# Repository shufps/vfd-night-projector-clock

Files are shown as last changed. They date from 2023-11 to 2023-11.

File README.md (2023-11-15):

# vfd-night-clock



## Description

The VFD Night Projector Clock is the first and only (at the moment and to my knowledge 😁) night projecting clock that uses a VFD display.

When receiving one of the NOS IVL2-7/5 displays, I noticed that the illuminated area could fit in about full-format (24x36mm) what was standard in analogue photography.

For this reason there are plenty of old lenses (e.g. with M42 threading) out there that almost cost nothing anymore although they have impressive technical properties like 1:2.8 with f=135.

Moreover, they have a flange focal distance of 45.46mm which allows to build a relatively compact casing.



So here it is ... 🥳

This image shows a comparison between my old radio clock with projector and the VFD night clock projector:



The brighness is perfect in the night 👌 (but ofc barely visible at day)

If everything is adjusted properly, you even can see the grid on the digits:



## Properties

There are some methods how a VFD can be operated. After some prior experience with VFDs this is one of the easiest methods:

- isolated 24 DCDC converter for anode voltage. The V+ is connected to GND, so you have -24V on the board
- the positive gate/segment voltage is +3.3V. You easily can switch the positive gate/segment voltage with BSS84s from a STM32 with no additional parts what is the easiest solution. This gives a total gate / segment voltage of 27.3V
- AC Filament drive is done with a full-bridge made of a two channel MOSFET driver. The output is AC coupled and pulled to about -22V. Bias is adjustable (even could be used to change the brightness)



## STM32 Software

The STM32 software currently only supports a json-rpc via USB virtual COM port (CDC). Buttons are currently unused 🙈

There is python code that can 

- measure the clock accuracy
- set the time
- set the display state and auto-switch on/off

This are small examples that nicely demonstrate how to use the json-rpc.

## 3D case



The case was designed in a way that no supports are needed. The upper part is simply clipped on the lower part.

<!--
Ode to VFD Displays (Chatti4 2023)

Oh, relics of an era long past,<br>
Vacuum Fluorescent Displays, you hold fast.<br>
Born in Soviet realms, a technological feast,<br>
Your glasspunk aesthetics have never ceased.<br>

In your cylindrical tubes, a dance of light,<br>
A greenish-blue hue, softly bright.<br>
Your glow, a whisper from history's tide,<br>
In old devices, you reside with pride.<br>

You are the silent storytellers, bold,<br>
Of times when technology wasn't so cold.<br>
Your luminescent charm, a visual delight,<br>
In the stillness of rooms, you're the night's light.<br>

Through you, numbers and words gracefully flow,<br>
A retro display, a nostalgic glow.<br>
Your enduring spirit, a testament to time,<br>
In the world of screens, you're a verse, a rhyme.<br>

VFD, in your glass cocoon you lay,<br>
A visual symphony in green and gray.<br>
A bridge from the past, to the present you lead,<br>
A piece of history, in every glowing bead.<br>

In the march of progress, you're a quiet ode,<br>
A reminder of a less digital road.<br>
VFD displays, in you, the past does reside,<br>
A beautiful, forgotten technological stride.<br>
-->

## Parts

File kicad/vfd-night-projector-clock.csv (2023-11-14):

# | Reference | Qty | Value | Footprint | DNP | OrderNr | Distributor
1 | C1, C5, C6, C9, C15 | 5 | 100n | Capacitor_SMD:C_0805_2012Metric
2 | C2, C8, C10, C11, C13 | 5 | 10µF/50V | Capacitor_SMD:C_1206_3216Metric |  | 1276-6736-1-ND | D
3 | C3, C4 | 2 | 6pF | Capacitor_SMD:C_0805_2012Metric |  | 311-1095-1-ND | D
4 | C7, C12 | 2 | 10µ/50V | Capacitor_SMD:CP_Elec_5x5.4 |  | 732-8451-1-ND | D
5 | C14 | 1 | 1µ/50V | Capacitor_SMD:C_1206_3216Metric |  | 1276-2719-1-ND | D
6 | J1 | 1 | SWD | myfootprints:PinHeader_IDC_2x05_P1.27mm_Vertical_SMD |  |  | X
7 | P1 | 1 | MYUSB_B | Connector_USB:USB_Micro-B_Amphenol_10103594-0001LF_Horizontal |  | 609-4050-1-ND | D
8 | Q1, Q2, Q3, Q4, Q5, Q6, Q7, Q8, Q9, Q10, Q11, Q12, Q13, Q14 | 14 | BSS84 | Package_TO_SOT_SMD:SOT-23
9 | R1, R2 | 2 | 1k | Resistor_SMD:R_0805_2012Metric
10 | R3, R5 | 2 | 15R | Resistor_SMD:R_2010_5025Metric |  | RMCF2010JT15R0CT-ND | D
11 | R4, R7, R11, R12, R13, R14, R15, R16, R17, R18, R19, R20, R21, R22 | 14 | 47k | Resistor_SMD:R_0805_2012Metric
12 | R6 | 1 | 36k | Resistor_SMD:R_0805_2012Metric
13 | R8 | 1 | x | Resistor_SMD:R_0805_2012Metric | DNP |  | -
14 | R9, R26 | 2 | 12R | Resistor_SMD:R_2010_5025Metric |  | RMCF2010JT12R0CT-ND | D
15 | R10, R29 | 2 | 10R | Resistor_SMD:R_2010_5025Metric |  | RMCF2010JT10R0CT-ND | D
16 | R23 | 1 | 100k | Resistor_SMD:R_0805_2012Metric
17 | R24, R25 | 2 | 10k | Resistor_SMD:R_0805_2012Metric
18 | R27, R28 | 2 | 22 | Resistor_SMD:R_0805_2012Metric
19 | RV1 | 1 | 10k | Potentiometer_SMD:Potentiometer_Bourns_3269W_Vertical |  | 3269W-1-103LF-ND | D
20 | SW3, SW4, SW5 | 3 | SW_SPST | Button_Switch_THT:SW_Tactile_SPST_Angled_PTS645Vx83-2LFS |  | CKN9121-ND | D
21 | U1 | 1 | IVL2-7_5 | myfootprints:ILV2-5_7 |  |  | X
22 | U2 | 1 | TLV9301xDBV | Package_TO_SOT_SMD:SOT-23-5 |  | 296-TLV9301IDBVRCT-ND | D
23 | U3 | 1 | STM32L052K6Tx | Package_QFP:LQFP-32_7x7mm_P0.8mm |  | 497-14904-ND | D
24 | U4 | 1 | 2EDN7524F | Package_SO:SO-8_3.9x4.9mm_P1.27mm |  | 2EDN7524FXTMA1CT-ND | D
25 | U5 | 1 | IES0105S24 | myfootprints:IES0105S24-dcdc |  | 1470-IES0105S24-ND | D
26 | U6 | 1 | LM1117MP-3.3 | Package_TO_SOT_SMD:SOT-223-3_TabPin2 |  | LM1117MPX-3.3/NOPBCT-ND | D
27 | Y1 | 1 | Crystal | Crystal:Crystal_SMD_EuroQuartz_EQ161-2Pin_3.2x1.5mm |  | 535-15021-1-ND | D

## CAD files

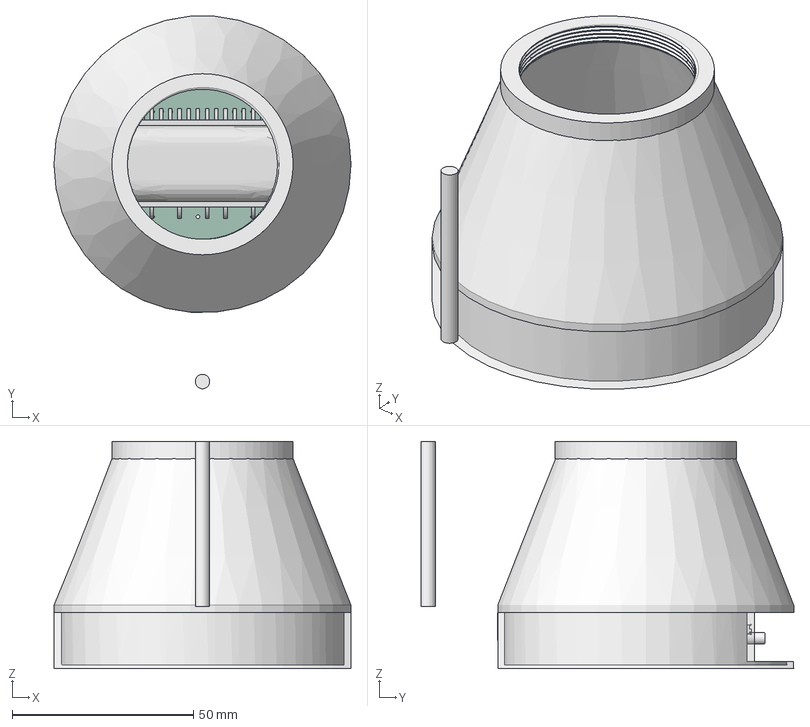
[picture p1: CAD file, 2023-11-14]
3d/case/case.FCStd
82.0 x 102.8 x 62.7 mm
Zylinder020
vfd1 PCB
M42test

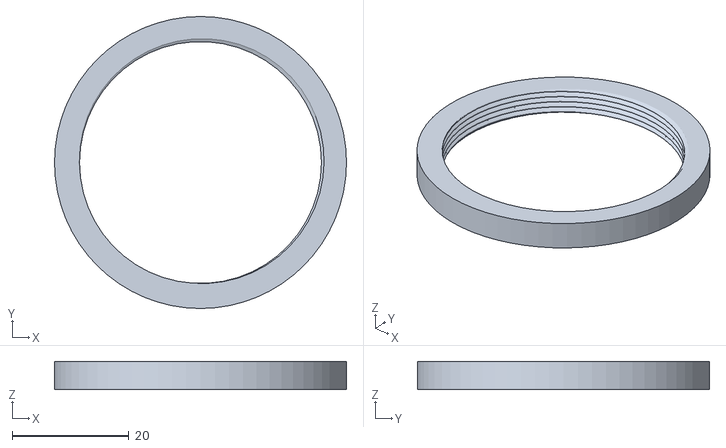
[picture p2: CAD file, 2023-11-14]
3d/openscad/M42test.stl
50.0 x 50.0 x 4.80

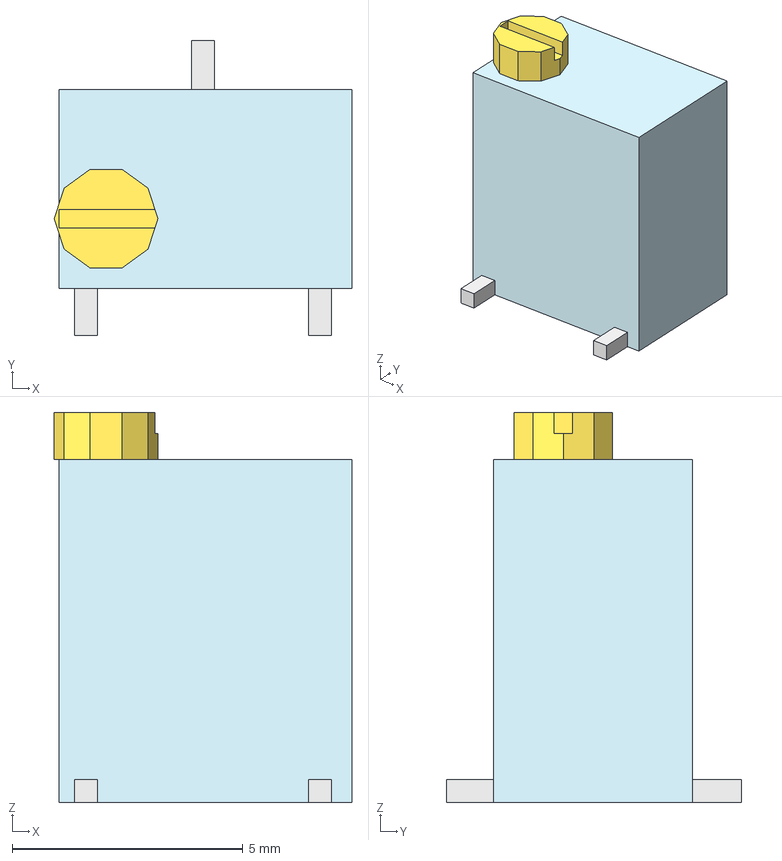
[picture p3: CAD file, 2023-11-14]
3d/3269-potentiometer.step
6.46 x 6.41 x 8.46 mm

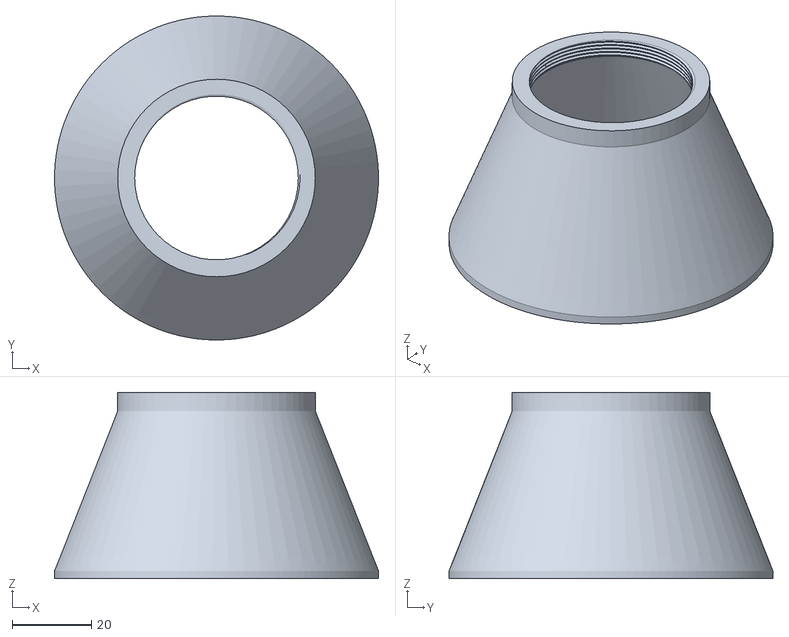
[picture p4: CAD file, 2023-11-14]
3d/case/case-top.stl
82.0 x 82.0 x 47.2

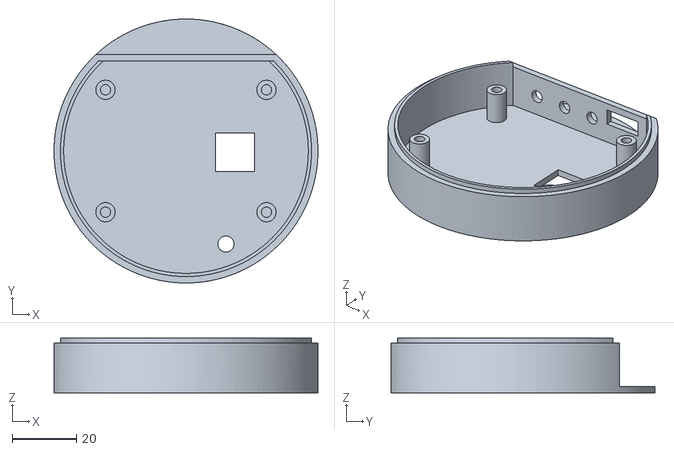
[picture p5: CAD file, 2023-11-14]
3d/case/case-bottom.stl
82.0 x 82.0 x 17.0

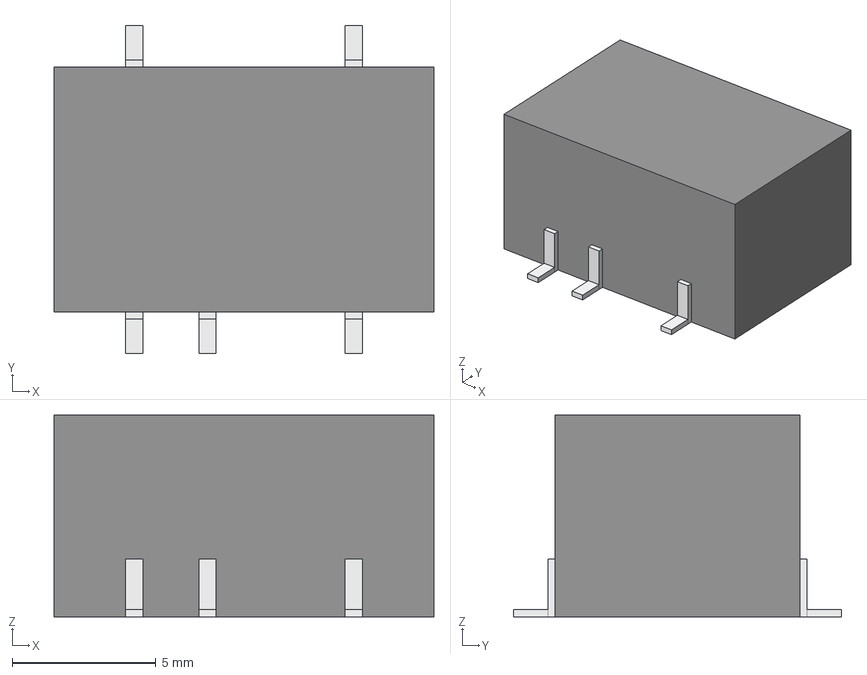
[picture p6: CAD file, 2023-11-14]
3d/dcdc.step
13.2 x 11.4 x 7.00 mm

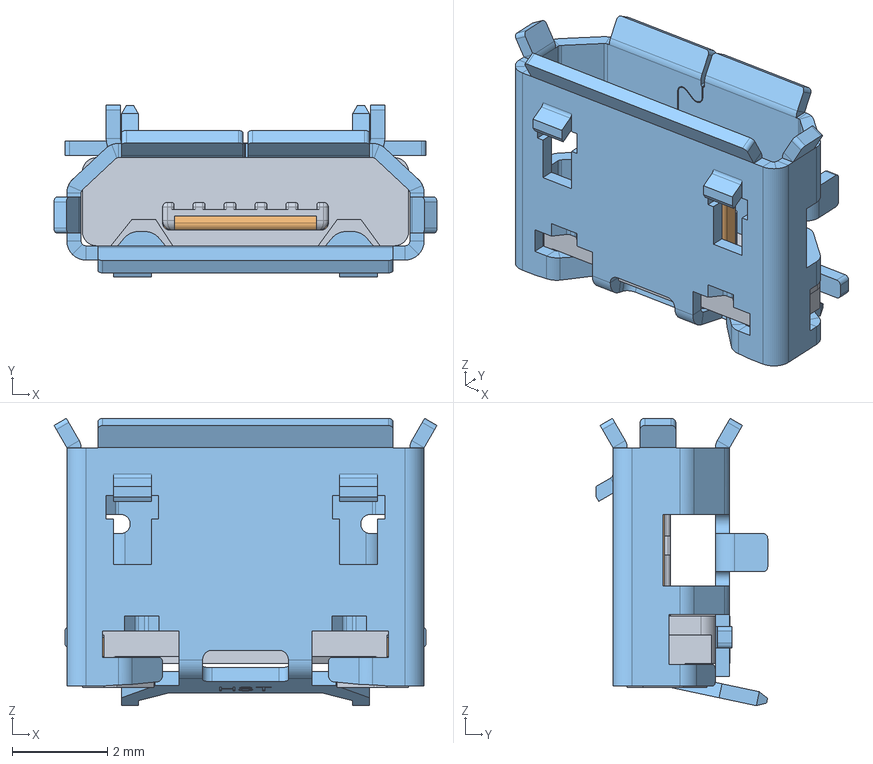
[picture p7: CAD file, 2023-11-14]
3d/10103594.step
8.04 x 3.60 x 6.03 mm
_0103594 (Solid)
_0103597 (Solid)
_0103596 (Solid)

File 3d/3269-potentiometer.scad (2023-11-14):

$fn=10;

color("lightblue") cube([6.35, 4.32, 7.44] );
color("gold") difference() {
    translate([1.02, 1.52, 7.44]) cylinder(d=2.25, h=1.02);
    translate([0, 1.52-0.2, 8]) cube([10, 0.4, 0.5]);
}
color("lightgray") {
    translate([6.25/2-2.54-0.5/2, -1.02, 0]) cube([0.5, 2.29, 0.5]);
    translate([6.25/2+2.54-0.5/2, -1.02, 0]) cube([0.5, 2.29, 0.5]);
    translate([6.25/2-0.5/2, -1.02+4.32-0.2, 0]) cube([0.5, 2.29, 0.5]);
    
}

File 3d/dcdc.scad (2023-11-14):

$fn=10;

module leg() {
    cube([0.6, 1.2, 0.25]);
    translate([0, 1.2, 0]) cube([0.6, 0.25, 2]);
}

color("#404040") cube([13.20, 8.5, 7], center=true);
color("lightgray") {
    translate([-2.54-1.27-0.3, -8.5/2-1.45, -3.5]) rotate([0, 0, 0]) leg();
    translate([-1.27-0.3, -8.5/2-1.45, -3.5]) rotate([0, 0, 0]) leg();
    translate([+2.54+1.27-0.3, -8.5/2-1.45, -3.5]) rotate([0, 0, 0]) leg();
    translate([+2.54+1.27+0.3, +8.5/2+1.45, -3.5]) rotate([0, 0, 180]) leg();
    translate([-2.54-1.27+0.3, +8.5/2+1.45, -3.5]) rotate([0, 0, 180]) leg();
}
//translate([0, 0, 0]) cube([5, 11.4, 1], center=true);

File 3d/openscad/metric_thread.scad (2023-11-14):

/*
 * ISO-standard metric threads, following this specification:
 *          http://en.wikipedia.org/wiki/ISO_metric_screw_thread
 *
 * Copyright 2017 Dan Kirshner - dan_kirshner@yahoo.com
 * This program is free software: you can redistribute it and/or modify
 * it under the terms of the GNU General Public License as published by
 * the Free Software Foundation, either version 3 of the License, or
 * (at your option) any later version.
 *
 * This program is distributed in the hope that it will be useful,
 * but WITHOUT ANY WARRANTY; without even the implied warranty of
 * MERCHANTABILITY or FITNESS FOR A PARTICULAR PURPOSE.  See the
 * GNU General Public License for more details.
 *
 * See <http://www.gnu.org/licenses/>.
 *
 * Version 2.3.  2017-08-31  Default for leadin: 0 (best for internal threads).
 * Version 2.2.  2017-01-01  Correction for angle; leadfac option.  (Thanks to
 *                           Andrew Allen <a2intl@gmail.com>.)
 * Version 2.1.  2016-12-04  Chamfer bottom end (low-z); leadin option.
 * Version 2.0.  2016-11-05  Backwards compatibility (earlier OpenSCAD) fixes.
 * Version 1.9.  2016-07-03  Option: tapered.
 * Version 1.8.  2016-01-08  Option: (non-standard) angle.
 * Version 1.7.  2015-11-28  Larger x-increment - for small-diameters.
 * Version 1.6.  2015-09-01  Options: square threads, rectangular threads.
 * Version 1.5.  2015-06-12  Options: thread_size, groove.
 * Version 1.4.  2014-10-17  Use "faces" instead of "triangles" for polyhedron
 * Version 1.3.  2013-12-01  Correct loop over turns -- don't have early cut-off
 * Version 1.2.  2012-09-09  Use discrete polyhedra rather than linear_extrude ()
 * Version 1.1.  2012-09-07  Corrected to right-hand threads!
 */

// Examples.
//
// Standard M8 x 1.
// metric_thread (diameter=8, pitch=1, length=4);

// Square thread.
// metric_thread (diameter=8, pitch=1, length=4, square=true);

// Non-standard: long pitch, same thread size.
//metric_thread (diameter=8, pitch=4, length=4, thread_size=1, groove=true);

// Non-standard: 20 mm diameter, long pitch, square "trough" width 3 mm,
// depth 1 mm.
//metric_thread (diameter=20, pitch=8, length=16, square=true, thread_size=6,
//               groove=true, rectangle=0.333);

// English: 1/4 x 20.
//english_thread (diameter=1/4, threads_per_inch=20, length=1);

// Tapered.  Example -- pipe size 3/4" -- per:
// http://www.engineeringtoolbox.com/npt-national-pipe-taper-threads-d_750.html
// english_thread (diameter=1.05, threads_per_inch=14, length=3/4, taper=1/16);

// Thread for mounting on Rohloff hub.
//difference () {
//   cylinder (r=20, h=10, $fn=100);
//
//   metric_thread (diameter=34, pitch=1, length=10, internal=true, n_starts=6);
//}


// ----------------------------------------------------------------------------
function segments (diameter) = min (50, ceil (diameter*6));


// ----------------------------------------------------------------------------
// diameter -    outside diameter of threads in mm. Default: 8.
// pitch    -    thread axial "travel" per turn in mm.  Default: 1.
// length   -    overall axial length of thread in mm.  Default: 1.
// internal -    true = clearances for internal thread (e.g., a nut).
//               false = clearances for external thread (e.g., a bolt).
//               (Internal threads should be "cut out" from a solid using
//               difference ()).
// n_starts -    Number of thread starts (e.g., DNA, a "double helix," has
//               n_starts=2).  See wikipedia Screw_thread.
// thread_size - (non-standard) axial width of a single thread "V" - independent
//               of pitch.  Default: same as pitch.
// groove      - (non-standard) subtract inverted "V" from cylinder (rather than
//               add protruding "V" to cylinder).
// square      - Square threads (per
//               https://en.wikipedia.org/wiki/Square_thread_form).
// rectangle   - (non-standard) "Rectangular" thread - ratio depth/(axial) width
//               Default: 1 (square).
// angle       - (non-standard) angle (deg) of thread side from perpendicular to
//               axis (default = standard = 30 degrees).
// taper       - diameter change per length (National Pipe Thread/ANSI B1.20.1
//               is 1" diameter per 16" length). Taper decreases from 'diameter'
//               as z increases.
// leadin      - 0 (default): no chamfer; 1: chamfer (45 degree) at max-z end;
//               2: chamfer at both ends, 3: chamfer at z=0 end.
// leadfac     - scale of leadin chamfer (default: 1.0 = 1/2 thread).
module metric_thread (diameter=8, pitch=1, length=1, internal=false, n_starts=1,
                      thread_size=-1, groove=false, square=false, rectangle=0,
                      angle=30, taper=0, leadin=0, leadfac=1.0)
{
   // thread_size: size of thread "V" different than travel per turn (pitch).
   // Default: same as pitch.
   local_thread_size = thread_size == -1 ? pitch : thread_size;
   local_rectangle = rectangle ? rectangle : 1;

   n_segments = segments (diameter);
   h = (square || rectangle) ? local_thread_size*local_rectangle/2 : local_thread_size / (2 * tan(angle));

   h_fac1 = (square || rectangle) ? 0.90 : 0.625;

   // External thread includes additional relief.
   h_fac2 = (square || rectangle) ? 0.95 : 5.3/8;

   tapered_diameter = diameter - length*taper;

   difference () {
      union () {
         if (! groove) {
            metric_thread_turns (diameter, pitch, length, internal, n_starts,
                                 local_thread_size, groove, square, rectangle, angle,
                                 taper);
         }

         difference () {

            // Solid center, including Dmin truncation.
            if (groove) {
               cylinder (r1=diameter/2, r2=tapered_diameter/2,
                         h=length, $fn=n_segments);
            } else if (internal) {
               cylinder (r1=diameter/2 - h*h_fac1, r2=tapered_diameter/2 - h*h_fac1,
                         h=length, $fn=n_segments);
            } else {

               // External thread.
               cylinder (r1=diameter/2 - h*h_fac2, r2=tapered_diameter/2 - h*h_fac2,
                         h=length, $fn=n_segments);
            }

            if (groove) {
               metric_thread_turns (diameter, pitch, length, internal, n_starts,
                                    local_thread_size, groove, square, rectangle,
                                    angle, taper);
            }
         }
      }

      // chamfer z=0 end if leadin is 2 or 3
      if (leadin == 2 || leadin == 3) {
         difference () {
            cylinder (r=diameter/2 + 1, h=h*h_fac1*leadfac, $fn=n_segments);

            cylinder (r2=diameter/2, r1=diameter/2 - h*h_fac1*leadfac, h=h*h_fac1*leadfac,
                      $fn=n_segments);
         }
      }

      // chamfer z-max end if leadin is 1 or 2.
      if (leadin == 1 || leadin == 2) {
         translate ([0, 0, length + 0.05 - h*h_fac1*leadfac]) {
            difference () {
               cylinder (r=diameter/2 + 1, h=h*h_fac1*leadfac, $fn=n_segments);
               cylinder (r1=tapered_diameter/2, r2=tapered_diameter/2 - h*h_fac1*leadfac, h=h*h_fac1*leadfac,
                         $fn=n_segments);
            }
         }
      }
   }
}


// ----------------------------------------------------------------------------
// Input units in inches.
// Note: units of measure in drawing are mm!
module english_thread (diameter=0.25, threads_per_inch=20, length=1,
                      internal=false, n_starts=1, thread_size=-1, groove=false,
                      square=false, rectangle=0, angle=30, taper=0, leadin=0,
                      leadfac=1.0)
{
   // Convert to mm.
   mm_diameter = diameter*25.4;
   mm_pitch = (1.0/threads_per_inch)*25.4;
   mm_length = length*25.4;

   echo (str ("mm_diameter: ", mm_diameter));
   echo (str ("mm_pitch: ", mm_pitch));
   echo (str ("mm_length: ", mm_length));
   metric_thread (mm_diameter, mm_pitch, mm_length, internal, n_starts,
                  thread_size, groove, square, rectangle, angle, taper, leadin,
                  leadfac);
}

// ----------------------------------------------------------------------------
module metric_thread_turns (diameter, pitch, length, internal, n_starts,
                            thread_size, groove, square, rectangle, angle,
                            taper)
{
   // Number of turns needed.
   n_turns = floor (length/pitch);

   intersection () {

      // Start one below z = 0.  Gives an extra turn at each end.
      for (i=[-1*n_starts : n_turns+1]) {
         translate ([0, 0, i*pitch]) {
            metric_thread_turn (diameter, pitch, internal, n_starts,
                                thread_size, groove, square, rectangle, angle,
                                taper, i*pitch);
         }
      }
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

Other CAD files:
3d/openscad/M42test.scad

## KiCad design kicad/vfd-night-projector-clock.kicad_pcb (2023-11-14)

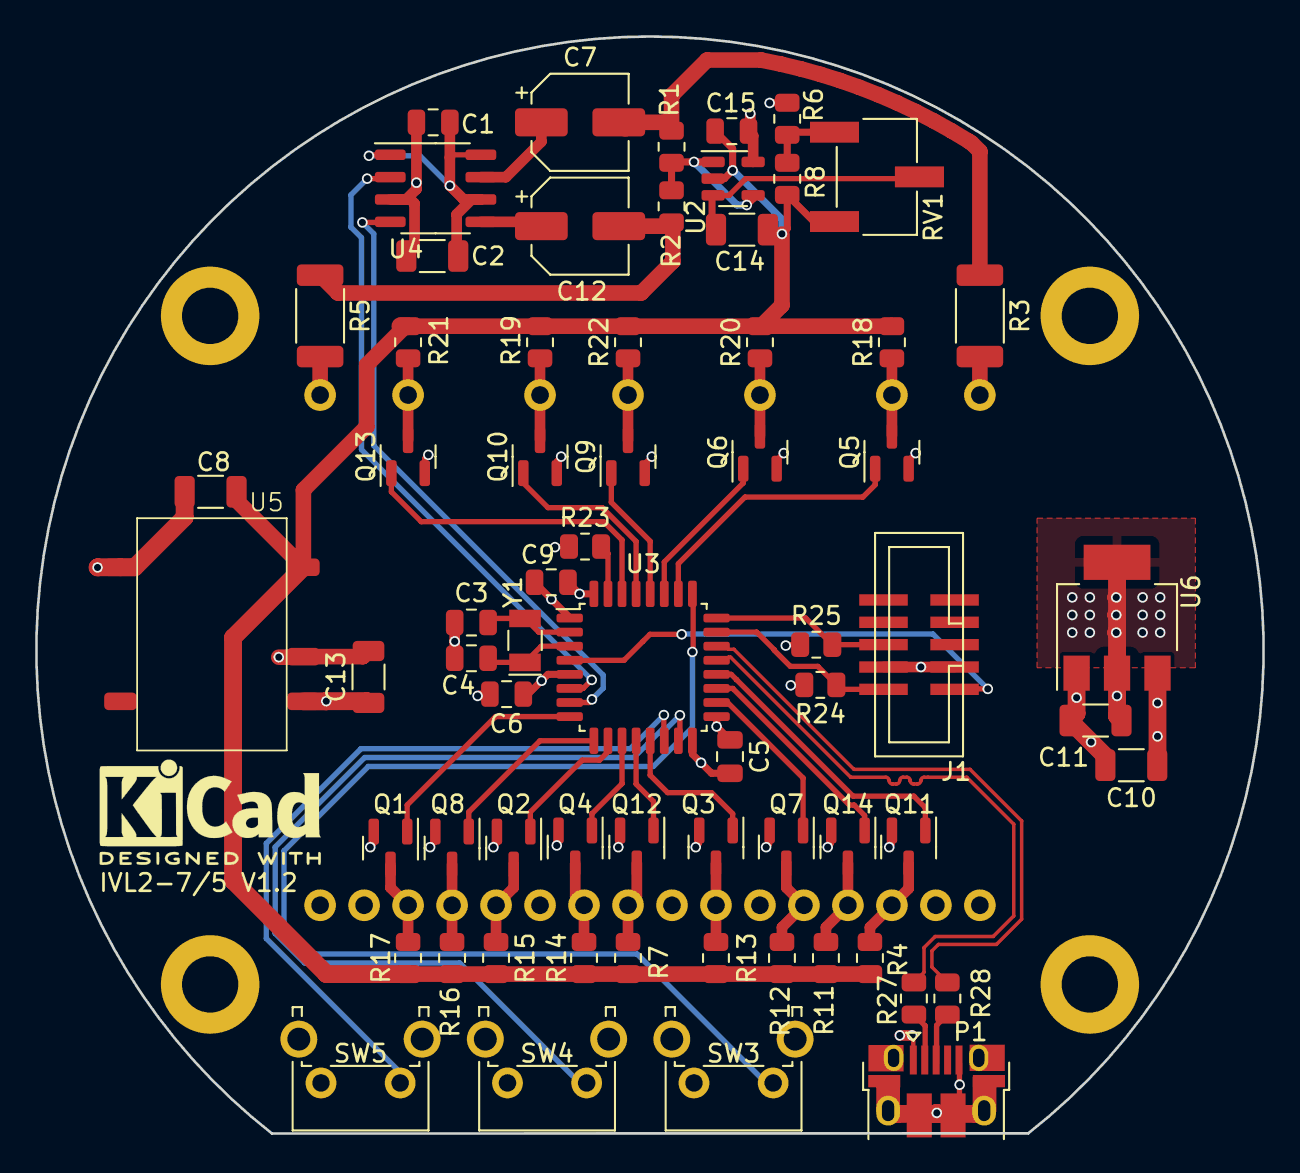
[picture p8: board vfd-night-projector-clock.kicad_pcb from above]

Board: 4 copper layers, 69.7 x 62.3 mm, 67 parts (1 on the bottom side), 56 nets.

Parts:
C1, C5, C6, C9, C15: 100n; C_0805_2012Metric
C2, C8, C10, C11, C13: 10µF/50V; C_1206_3216Metric
C3, C4: 6pF; C_0805_2012Metric
C7, C12: 10µ/50V; CP_Elec_5x5.4
C14: 1µ/50V; C_1206_3216Metric
J1: SWD; PinHeader_IDC_2x05_P1.27mm_Vertical_SMD
P1: MYUSB_B; USB_Micro-B_Amphenol_10103594-0001LF_Horizontal
Q1, Q2, Q3, Q4, Q5, Q6, Q7, Q8, Q9, Q10, Q11, Q12, Q13, Q14: BSS84; SOT-23
R1, R2: 1k; R_0805_2012Metric
R3, R5: 15R; R_2010_5025Metric
R4, R7, R11, R12, R13, R14, R15, R16, R17, R18, R19, R20, R21, R22: 47k; R_0805_2012Metric
R6: 36k; R_0805_2012Metric
R8: x; R_0805_2012Metric
R23: 100k; R_0805_2012Metric
R24, R25: 10k; R_0805_2012Metric
R27, R28: 22; R_0805_2012Metric
RV1: 10k; Potentiometer_Bourns_3269W_Vertical
SW3, SW4, SW5: SW_SPST; SW_Tactile_SPST_Angled_PTS645Vx83-2LFS
U1: IVL2-7_5; ILV2-5_7
U2: TLV9301xDBV; SOT-23-5
U3: STM32L052K6Tx; LQFP-32_7x7mm_P0.8mm
U4: 2EDN7524F; SO-8_3.9x4.9mm_P1.27mm
U5: IES0105S24; IES0105S24-dcdc
U6: LM1117MP-3.3; SOT-223-3_TabPin2
Y1: Crystal; Crystal_SMD_EuroQuartz_EQ161-2Pin_3.2x1.5mm

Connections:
+3V3: C5.1, C6.1, C9.1, C11.1, Q1.2 (S), Q2.2 (S), Q3.2 (S), Q4.2 (S), Q5.2 (S), Q6.2 (S), Q7.2 (S), Q8.2 (S), Q9.2 (S), Q10.2 (S), Q11.2 (S), Q12.2 (S), Q13.2 (S), Q14.2 (S), R24.2, U3.1 (VDD), U3.5 (VDDA), U3.17 (VDD), U6.2 (VO)
+5V: C1.1, C2.2, C10.1, C13.2, P1.1 (VCC), U4.1 (ENA), U4.6 (VDD), U4.8 (ENB), U5.2 (+VIN), U6.3 (VI)
-24V: C8.1, C14.2, C15.2, R4.2, R7.2, R8.1, R11.2, R12.2, R13.2, R14.2, R15.2, R16.2, R17.2, R18.2, R19.2, R20.2, R21.2, R22.2, RV1.3, U2.2 (V-), U5.4 (-VOUT)
/GATE_1: Q5.3 (D), R18.1, U1.22 (C1)
/GATE_2: Q6.3 (D), R20.1, U1.21 (C2)
/GATE_3: Q9.3 (D), R22.1, U1.20 (C3)
/GATE_4: Q10.3 (D), R19.1, U1.19 (C4)
/GATE_5: Q13.3 (D), R21.1, U1.18 (C5)
/LL_GATE_1: Q5.1 (G), U3.26 (PB3)
/LL_GATE_2: Q6.1 (G), U3.27 (PB4)
/LL_GATE_3: Q9.1 (G), U3.28 (PB5)
/LL_GATE_4: Q10.1 (G), U3.29 (PB6)
/LL_GATE_5: Q13.1 (G), U3.30 (PB7)
/LL_SEG_A: Q1.1 (G), U3.8 (PA2)
/LL_SEG_B: Q2.1 (G), U3.10 (PA4)
/LL_SEG_C: Q3.1 (G), U3.13 (PA7)
/LL_SEG_D: Q4.1 (G), U3.11 (PA5)
/LL_SEG_DP1: Q11.1 (G), U3.20 (PA10)
/LL_SEG_DP2: Q12.1 (G), U3.12 (PA6)
/LL_SEG_E: Q7.1 (G), U3.18 (PA8)
/LL_SEG_F: Q8.1 (G), U3.9 (PA3)
/LL_SEG_G: Q14.1 (G), U3.19 (PA9)
/SEG_A: Q1.3 (D), R17.1, U1.14 (a)
/SEG_B: Q2.3 (D), R15.1, U1.12 (b)
/SEG_C: Q3.3 (D), R13.1, U1.7 (c)
/SEG_D: Q4.3 (D), R14.1, U1.10 (d)
/SEG_DP1: Q11.3 (D), R4.1, U1.3 (DP1)
/SEG_DP2: Q12.3 (D), R7.1, U1.9 (DP2)
/SEG_E: Q7.3 (D), R12.1, U1.5 (e)
/SEG_F: Q8.3 (D), R16.1, U1.13 (f)
/SEG_G: Q14.3 (D), R11.1, U1.4 (g)
ARM_NRST: J1.1, U3.4 (NRST)
ARM_SWCLK: J1.6, R25.2, U3.24 (PA14)
ARM_SWDIO: J1.2, R24.1, U3.23 (PA13)
FIL1: R3.2, U1.23 (F1)
FIL2: R5.2, U1.17 (F2)
FILDRV1: U3.6 (PA0), U4.2 (INA)
FILDRV2: U3.7 (PA1), U4.4 (INB)
GND: C1.2, C2.1, C3.1, C4.1, C5.2, C6.2, C8.2, C9.2, C10.2, C11.2, C13.1, C15.1, J1.3, J1.4, P1.5 (GND), P1.6 (shield), R6.2, R23.1, R25.1, SW3.2 (B), SW4.2 (B), SW5.2 (B), U2.5 (V+), U3.16 (VSS), U3.32 (VSS), U4.3 (GND), U5.1 (-VIN), U5.5 (+VOUT), U6.1 (GND)
unnamed: C7.2, R1.2, R3.1
unnamed: C12.2, R2.1, R5.1
unnamed: P1.3 (D+), R28.2
unnamed: P1.2 (D-), R27.2
unnamed: R6.1, R8.2, RV1.1
unnamed: C14.1, RV1.2, U2.3 (+)
unnamed: R1.1, R2.2, U2.1, U2.4 (-)
unnamed: R23.2, U3.31 (BOOT0)
unnamed: C3.2, U3.2 (PC14), Y1.2
unnamed: C4.2, U3.3 (PC15), Y1.1
unnamed: C7.1, U4.7 (OUTA)
unnamed: C12.1, U4.5 (OUTB)
SW1: SW3.1 (A), U3.25 (PA15)
SW2: SW4.1 (A), U3.15 (PB1)
SW3: SW5.1 (A), U3.14 (PB0)
USB_D+: R28.1, U3.22 (PA12)
USB_D-: R27.1, U3.21 (PA11)

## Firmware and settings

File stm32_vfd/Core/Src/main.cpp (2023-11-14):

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
/* Includes ------------------------------------------------------------------*/
#include "main.h"
#include "usb_device.h"

/* USER CODE BEGIN Includes */
#include "rtc.h"
#include "usb.h"
#include "json.h"
// Bit encoding in rawdata

#define SEGA GPIO_PIN_2
#define SEGB GPIO_PIN_4
#define SEGC GPIO_PIN_7
#define SEGD GPIO_PIN_5
#define SEGE GPIO_PIN_8
#define SEGF GPIO_PIN_3
#define SEGG GPIO_PIN_9
#define SEGDP1 GPIO_PIN_10
#define SEGDP2 GPIO_PIN_6

#define NUM_SEGMENTS 9

uint16_t segments[NUM_SEGMENTS] = {SEGA, SEGB, SEGC,   SEGD,  SEGE,
                                   SEGF, SEGG, SEGDP1, SEGDP2};

#define GATE0 GPIO_PIN_3
#define GATE1 GPIO_PIN_4
#define GATE2 GPIO_PIN_5
#define GATE3 GPIO_PIN_6
#define GATE4 GPIO_PIN_7

#define NUM_GATES 5

uint16_t gates[NUM_GATES] = {GATE0, GATE1, GATE2, GATE3, GATE4};

// raw segment data definitions for numbers, cursor, dash and point
uint16_t digits[20] = {
    SEGA | SEGB | SEGC | SEGD | SEGE | SEGF,
    SEGB | SEGC,
    SEGA | SEGB | SEGG | SEGE | SEGD,
    SEGA | SEGB | SEGC | SEGD | SEGG,
    SEGF | SEGG | SEGB | SEGC,
    SEGA | SEGF | SEGG | SEGC | SEGD,
    SEGA | SEGF | SEGE | SEGD | SEGC | SEGG,
    SEGA | SEGB | SEGC,
    SEGA | SEGB | SEGC | SEGD | SEGE | SEGF | SEGG,
    SEGA | SEGB | SEGC | SEGD | SEGF | SEGG,
    SEGA | SEGB | SEGC | SEGE | SEGF | SEGG,        // 0xa
    SEGA | SEGB | SEGC | SEGD | SEGE | SEGF | SEGG, // 0xb
    SEGA | SEGB | SEGC | SEGD,                      // 0xc
    SEGA | SEGB | SEGC | SEGD | SEGE | SEGF,        // 0xd
    SEGA | SEGF | SEGE | SEGD | SEGG,               // 0xe
    SEGA | SEGF | SEGE | SEGG,                      // 0xf
    SEGD,                                           // cursor  0x10
    SEGG,                                           // dash 0x11
    0,                                              // empty 0x12
    SEGDP1 | SEGDP2,                                // h:m separator
};

// default display "  -  -  "
uint16_t display[5] = {2, 3, 19, 4, 5};
uint16_t rawdata[5];
uint32_t systick = 0;

extern control_t control;
/* USER CODE END Includes */

RTC_HandleTypeDef hrtc;

TIM_HandleTypeDef htim2;
TIM_HandleTypeDef htim21;

extern "C" void SystemClock_Config(void);
static void MX_GPIO_Init(void);
static void MX_RTC_Init(void);
static void MX_TIM2_Init(void);
static void MX_TIM21_Init(void);
/* USER CODE BEGIN 0 */

volatile uint8_t toggle = 0;
volatile int ctr = 0;
volatile int muxflag = 1;
volatile int trigger_second = 0;

void HAL_TIM_PeriodElapsedCallback(TIM_HandleTypeDef *htim) {
  if (htim == &htim21) {
    muxflag = 1;
  }
}

void HAL_RTCEx_WakeUpTimerEventCallback(RTC_HandleTypeDef *hrtc) {
  trigger_second = 1;
}

int filament_state = 1;

void filament_driver_enabled(int state) {
  if (state != filament_state) {
    if (state) {
      HAL_TIM_PWM_Start(&htim2, TIM_CHANNEL_1);
      HAL_TIM_PWM_Start(&htim2, TIM_CHANNEL_2);
    } else {
      HAL_TIM_PWM_Stop(&htim2, TIM_CHANNEL_1);
      HAL_TIM_PWM_Stop(&htim2, TIM_CHANNEL_2);
    }
  }
  filament_state = state;
}

extern USBD_HandleTypeDef hUsbDeviceFS;
/* USER CODE END 0 */

/**
 * @brief  The application entry point.
 * @retval int
 */
int main(void) {
  /* USER CODE BEGIN 1 */
  toggle = 0;
  /* USER CODE END 1 */

  /* MCU Configuration--------------------------------------------------------*/

  /* Reset of all peripherals, Initializes the Flash interface and the Systick.
   */
  HAL_Init();

  /* Configure the system clock */
  SystemClock_Config();

  /* Initialize all configured peripherals */
  MX_GPIO_Init();
  MX_RTC_Init();
  MX_TIM2_Init();
  MX_TIM21_Init();
  MX_USB_DEVICE_Init();
  /* Infinite loop */
  /* USER CODE BEGIN WHILE */
  int muxgate = 0;
  RTC_DateTypeDef date;
  RTC_TimeTypeDef time;
  // init_rtc();
  uint32_t ticks = 0;

  control.state = 1;
  control.hour_on = 0;
  control.minute_on = 0;
  control.hour_off = 0;
  control.minute_off = 0;

  while (1) {
    /* USER CODE END WHILE */

    /* USER CODE BEGIN 3 */

    if (trigger_second) {
      trigger_second = 0;
      ticks = systick;

      get_rtc(&date, &time);
      display[4] = time.Minutes % 10;
      display[3] = time.Minutes / 10;
      display[1] = time.Hours % 10;
      display[0] = time.Hours / 10;

      // power control
      if (!(control.hour_on == control.hour_off && control.minute_on == control.minute_off)) {
        if (time.Hours == control.hour_on && time.Minutes == control.minute_on) {
          control.state = 1;
        }
        if (time.Hours == control.hour_off && time.Minutes == control.minute_off) {
          control.state = 0;
        }
      }
      filament_driver_enabled(control.state);
    }

    if (systick - ticks > 500) {
      display[2] = 18;
    } else {
      display[2] = 19;
    }

    if (muxflag) {
      muxflag = 0;
      muxgate++;
      if (muxgate == NUM_GATES)
        muxgate = 0;

      for (int i = 0; i < NUM_GATES; i++) {
        rawdata[i] = digits[display[i]];
      }

      // mirror display
      // flipping segments b and c and reversing order should be enough
      uint16_t mirrored[5];
      for (int i = 0; i < NUM_GATES; i++) {
        uint16_t data = rawdata[NUM_GATES - 1 - i];

        mirrored[i] = data & ~(SEGB | SEGC | SEGE | SEGF);

        mirrored[i] |= ((data & SEGB) ? SEGF : 0) | ((data & SEGC) ? SEGE : 0) |
                       ((data & SEGE) ? SEGC : 0) | ((data & SEGF) ? SEGB : 0);
      }

      uint16_t gates_set =
          (GATE0 | GATE1 | GATE2 | GATE3 | GATE4) & ~gates[muxgate];
      uint16_t gates_reset = gates[muxgate];

      HAL_GPIO_WritePin(GPIOB, gates_set, GPIO_PIN_SET);
      HAL_GPIO_WritePin(GPIOB, gates_reset, GPIO_PIN_RESET);

      uint16_t segments_set = 0;
      uint16_t segments_reset = 0;

      for (int i = 0; i < NUM_SEGMENTS; i++) {
        if (!(mirrored[muxgate] & segments[i])) {
          segments_set |= segments[i];
        } else {
          segments_reset |= segments[i];
        }
      }
      HAL_GPIO_WritePin(GPIOA, segments_set, GPIO_PIN_SET);
      HAL_GPIO_WritePin(GPIOA, segments_reset, GPIO_PIN_RESET);
    }

    usb_loop();
  }
  /* USER CODE END 3 */
}

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


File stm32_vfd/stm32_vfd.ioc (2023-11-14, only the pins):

Mcu.UserName=STM32L052K6Tx
PA12.Signal=USB_DP
PB6.Signal=GPIO_Output
PB7.Signal=GPIO_Output
PA8.Signal=GPIO_Output
PA0.Signal=S_TIM2_CH1
PB1.Signal=GPIO_Input
PA6.Signal=GPIO_Output
PA10.Signal=GPIO_Output
PA15.Signal=GPIO_Input
PB4.Signal=GPIO_Output
PA3.Signal=GPIO_Output
PC14-OSC32_IN.Signal=RCC_OSC32_IN
PA13.Signal=SYS_SWDIO
PA9.Signal=GPIO_Output
PC15-OSC32_OUT.Signal=RCC_OSC32_OUT
PA1.Signal=S_TIM2_CH2
PA5.Signal=GPIO_Output
PA2.Signal=GPIO_Output
PB3.Signal=GPIO_Output
PA4.Signal=GPIO_Output
PB5.Signal=GPIO_Output
PA11.Signal=USB_DM
PA14.Signal=SYS_SWCLK
PB0.Signal=GPIO_Input
PA7.Signal=GPIO_Output

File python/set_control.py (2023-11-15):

import serial
import json
import time
from datetime import datetime
import pytz

# Setup serial communication
ser = serial.Serial('/dev/ttyACM0', 115200, timeout=1)

def send_request(request):
    # Convert dictionary to JSON string and append line breaks
    request_str = json.dumps(request) + "\r\n"
#    print("request: "+request_str)
    # Write request to serial port
    ser.write(request_str.encode('utf-8'))
    # Read response from serial port
    response_str = ser.read_until().decode('utf-8')
#    print("response: "+response_str)
    # Parse response string to dictionary
    response = json.loads(response_str)
    return response

def main():
    # Get current date and time in CET/Berlin timezone
    berlin_tz = pytz.timezone('Europe/Berlin')
    now = datetime.now(berlin_tz)

    # Record the initial time
    initial_time = now

    state = 1
    hour_on = 20
    minute_on = 0
    hour_off = 8
    minute_off = 0

    # Send initial request to set date and time
    initial_request = {
        "jsonrpc": "2.0",
        "id": "1",
        "method": "control",
        "params": {
            "state": state,
            "hour-on": hour_on,
            "minute-on": minute_on,
            "hour-off": hour_off,
            "minute-off": minute_off
        }
    }
    response = send_request(initial_request)
    print(response)  # Expecting: {"jsonrpc":"2.0","id":"1","result":"ok"}

if __name__ == "__main__":
    try:
        main()
    except KeyboardInterrupt:
        ser.close()  # Ensure the serial connection is closed upon exiting

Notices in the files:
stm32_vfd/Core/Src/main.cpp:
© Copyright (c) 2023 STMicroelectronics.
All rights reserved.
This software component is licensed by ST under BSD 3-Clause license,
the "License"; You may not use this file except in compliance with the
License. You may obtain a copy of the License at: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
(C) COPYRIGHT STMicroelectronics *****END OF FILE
